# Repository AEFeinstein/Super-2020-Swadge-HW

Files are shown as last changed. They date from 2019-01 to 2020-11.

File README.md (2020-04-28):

# Super 2020 Swadge Hardware

This repo contains hardware files for the Super 2020 Barrel and Banana Swadges, as well as the Swadge Programmer and the Swadge Devkit. [KiCad](https://www.kicad-pcb.org/) is used to work with the project files. [Inkscape](https://inkscape.org/) is used to work with the SVG vectors.

The corresponding hardware repository for the Super 2020 Swadge Firmware [can be found here](https://github.com/AEFeinstein/Super-2020-Swadge-FW).

The Barrel and Banana use the same schematic:
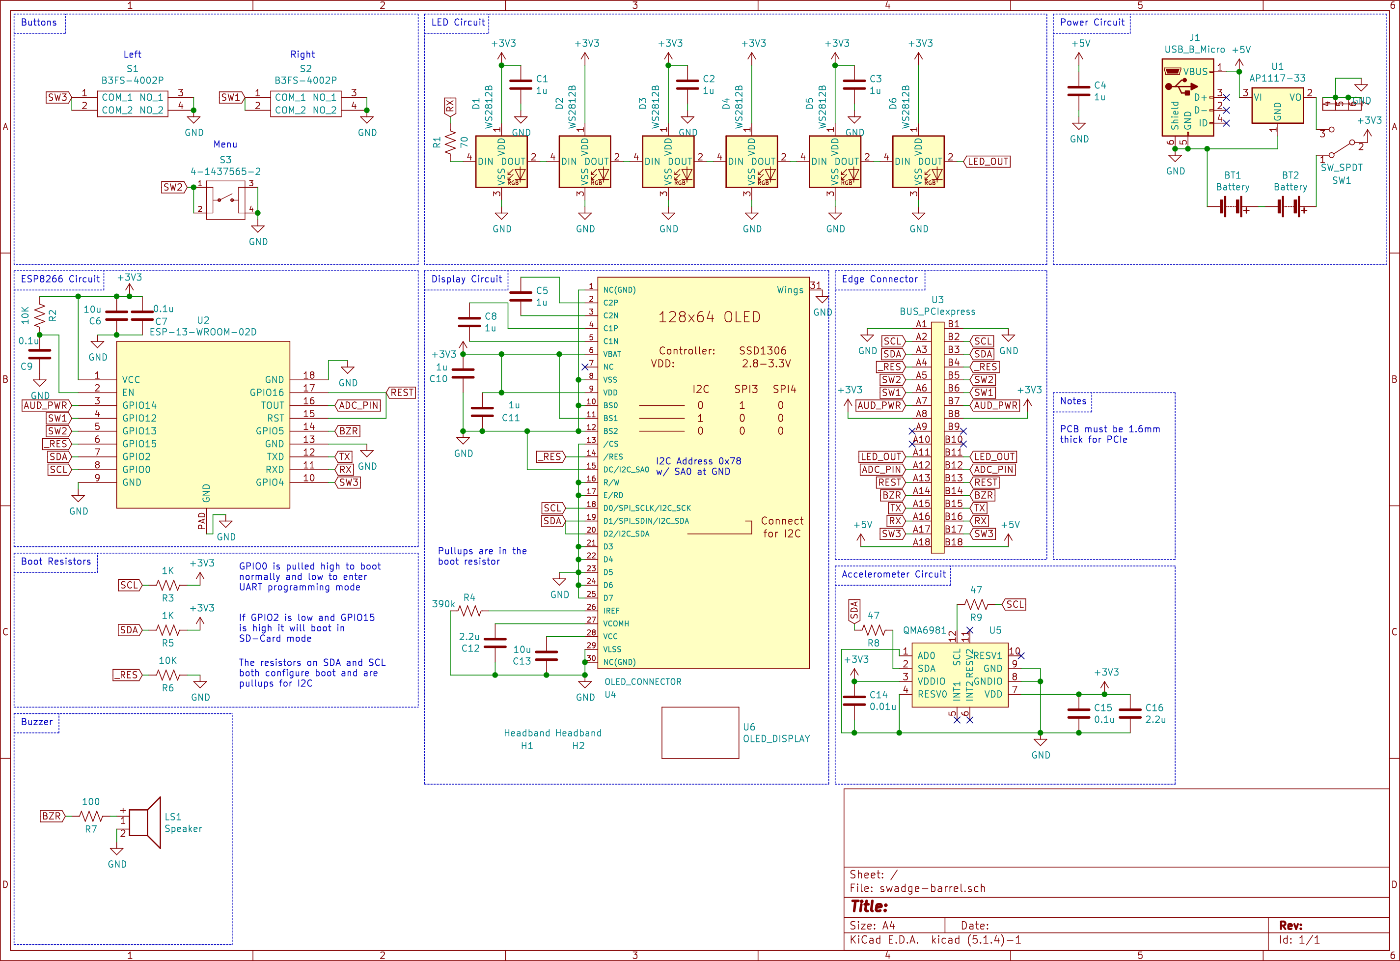
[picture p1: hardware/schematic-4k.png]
Schematic


View this project on [CADLAB.io](https://cadlab.io/project/1918).

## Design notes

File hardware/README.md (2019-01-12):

More libraries can be found at https://github.com/kitspace/kicad_footprints

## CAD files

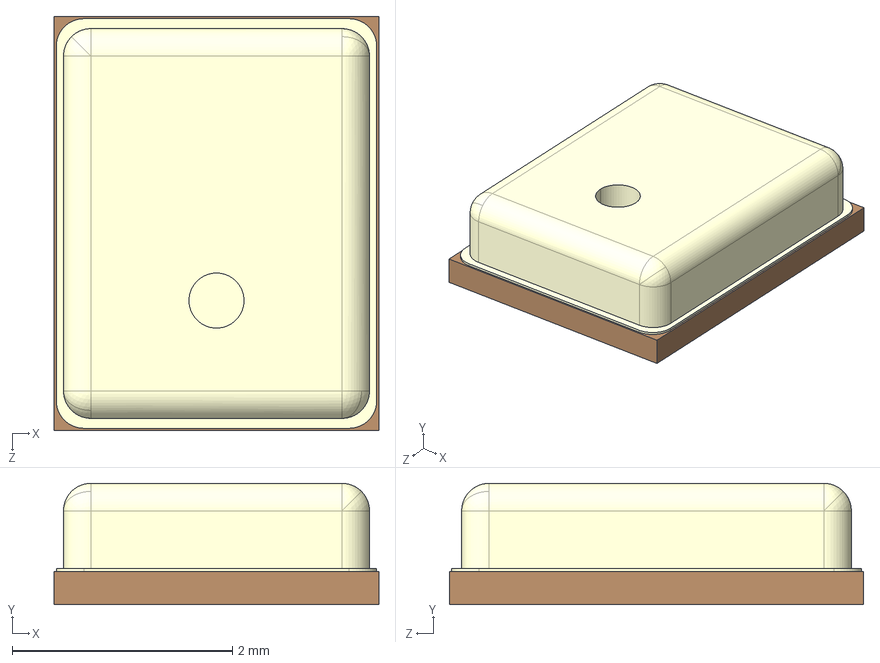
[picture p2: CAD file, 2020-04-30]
hardware/kicad-libs/package3d/AM4311T42A0.step
2.95 x 1.10 x 3.76 mm

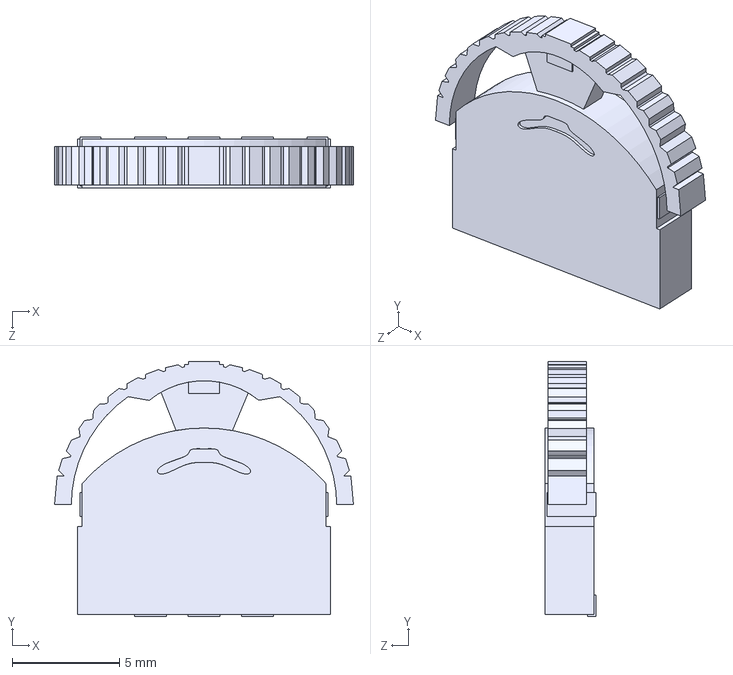
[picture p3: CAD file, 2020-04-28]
hardware/kicad-libs/package3d/NAV_SWITCH.STEP
14.0 x 11.9 x 2.40 mm

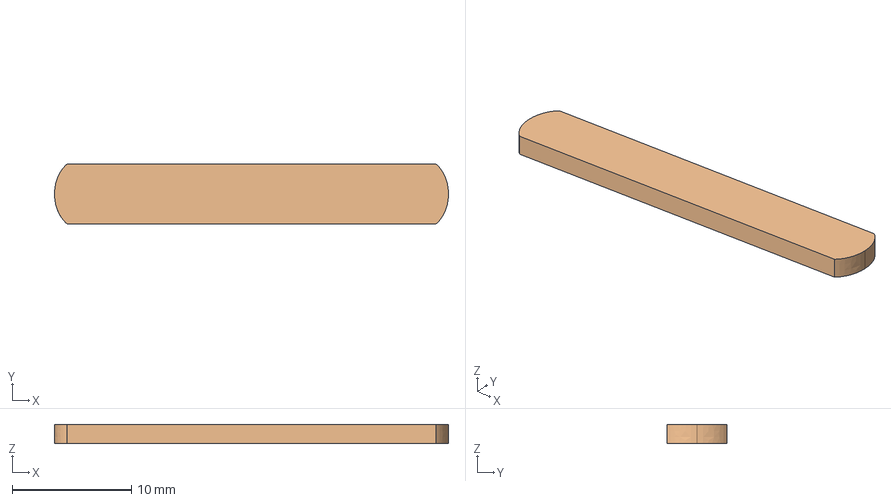
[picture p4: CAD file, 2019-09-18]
hardware/kicad-libs/package3d/headband.step
33.0 x 5.00 x 1.60 mm

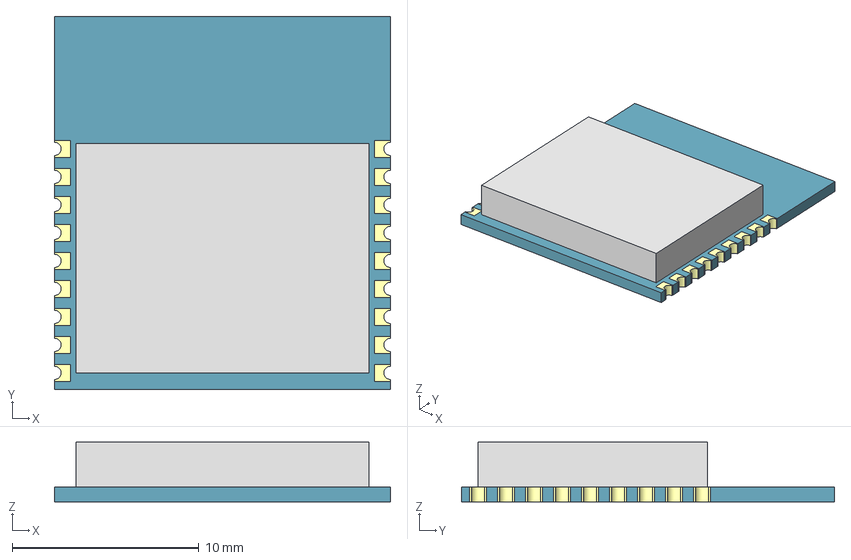
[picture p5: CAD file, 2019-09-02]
hardware/kicad-libs/package3d/ESP-WROOM-02D.stp
18.0 x 20.0 x 3.20 mm

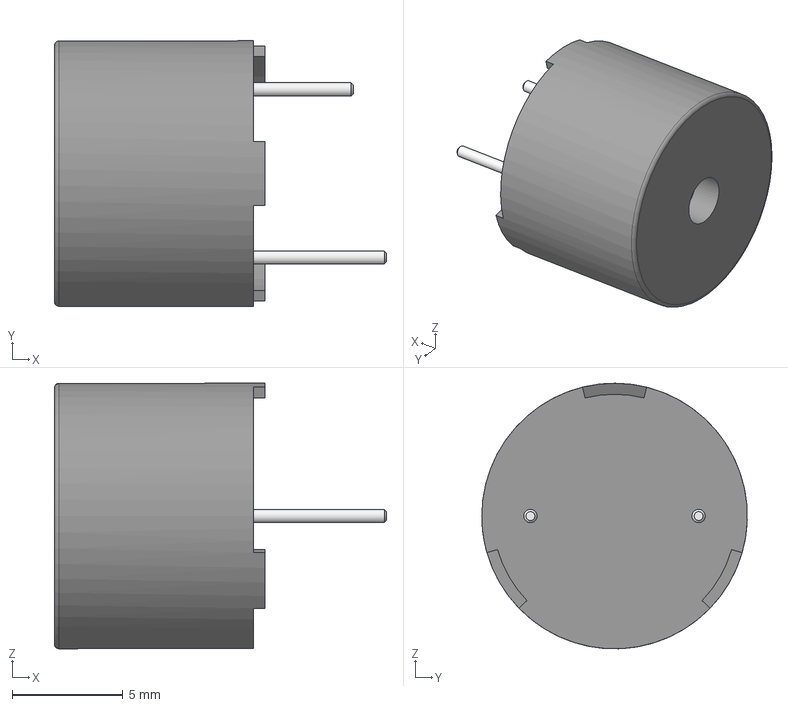
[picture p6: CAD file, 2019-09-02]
hardware/kicad-libs/package3d/Buzzer.step
15.0 x 12.0 x 12.0 mm

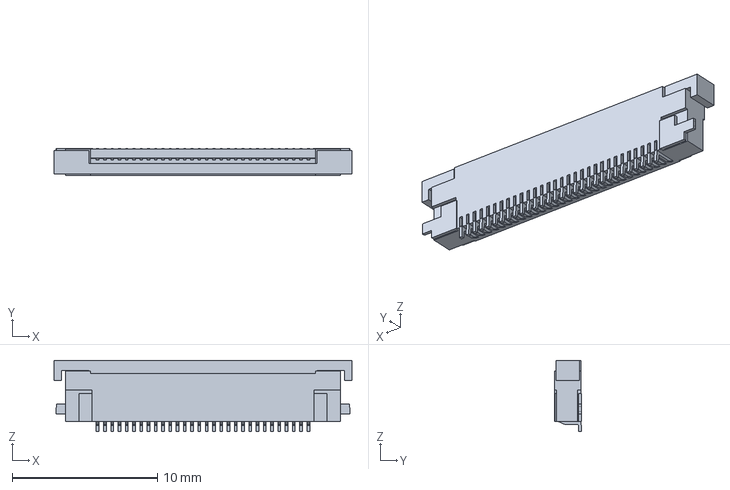
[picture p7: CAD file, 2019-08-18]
hardware/kicad-libs/package3d/ssfv30r_3stlf.stp
20.5 x 1.87 x 4.90 mm

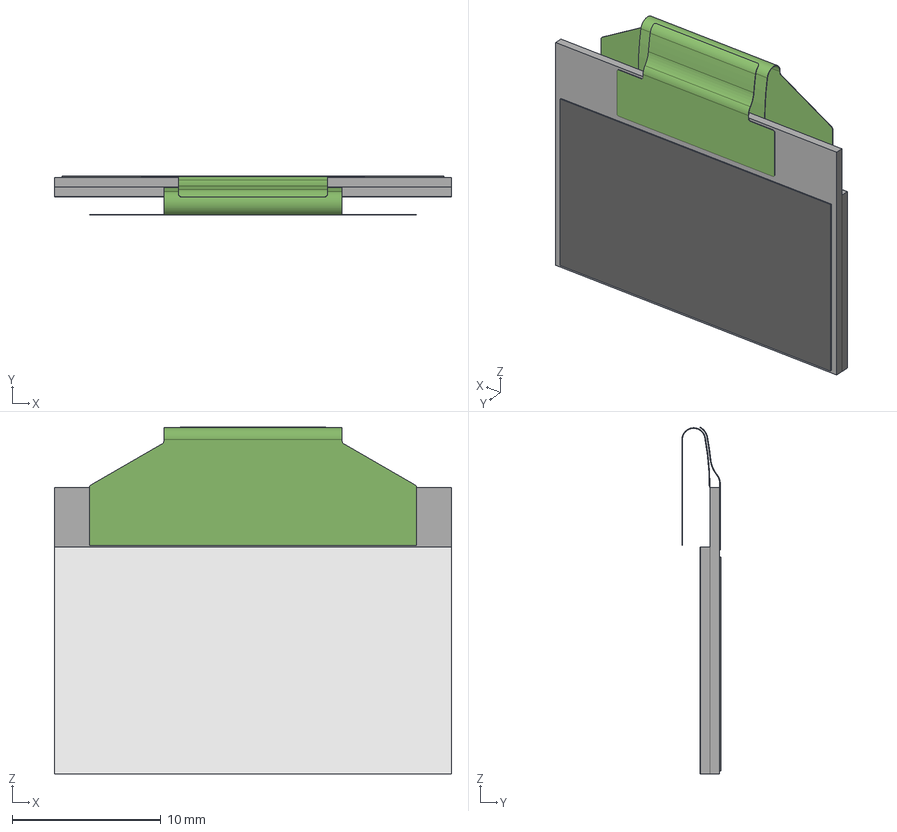
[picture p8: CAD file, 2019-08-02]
hardware/kicad-libs/package3d/oled_curved.step
26.7 x 2.65 x 23.3 mm

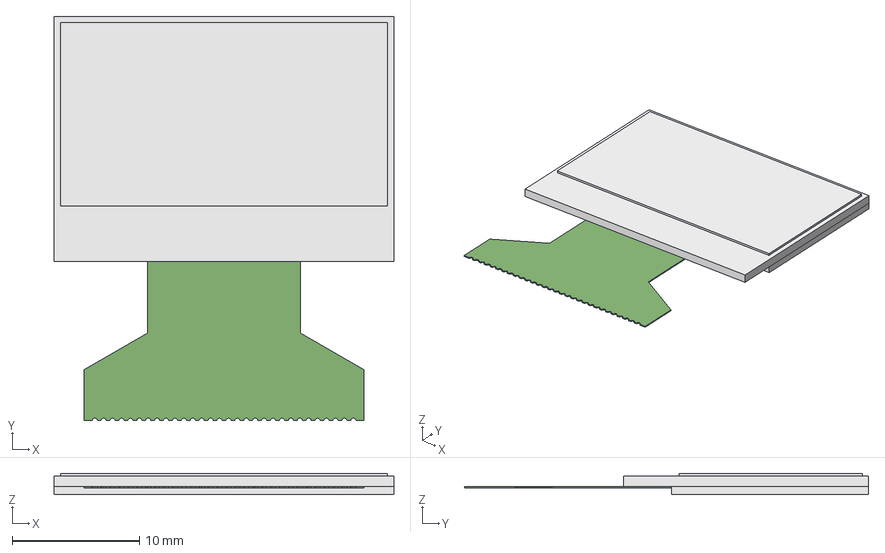
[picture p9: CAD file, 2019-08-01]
hardware/kicad-libs/package3d/oled.FCStd
26.7 x 31.8 x 1.65 mm
Polarizer
Panel
Cap

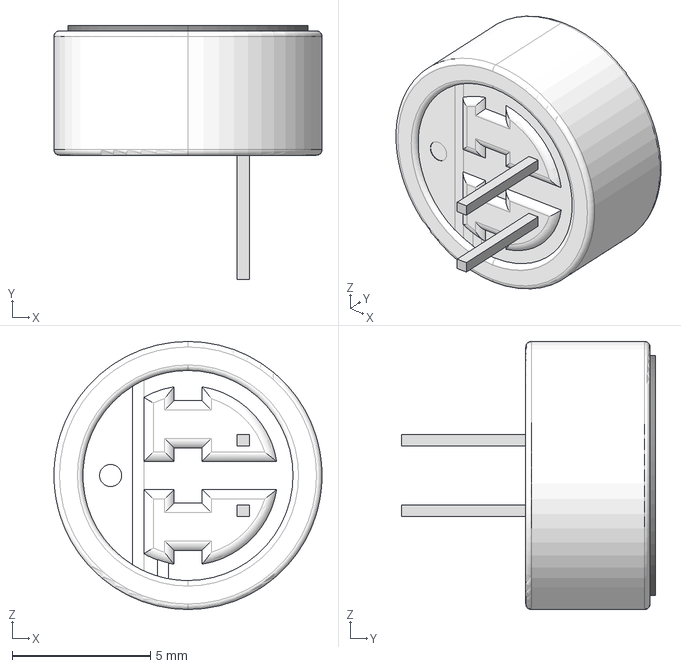
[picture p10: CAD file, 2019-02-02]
hardware/kicad-libs/package3d/CMA-4544PF-W.stp
9.70 x 9.20 x 9.70 mm

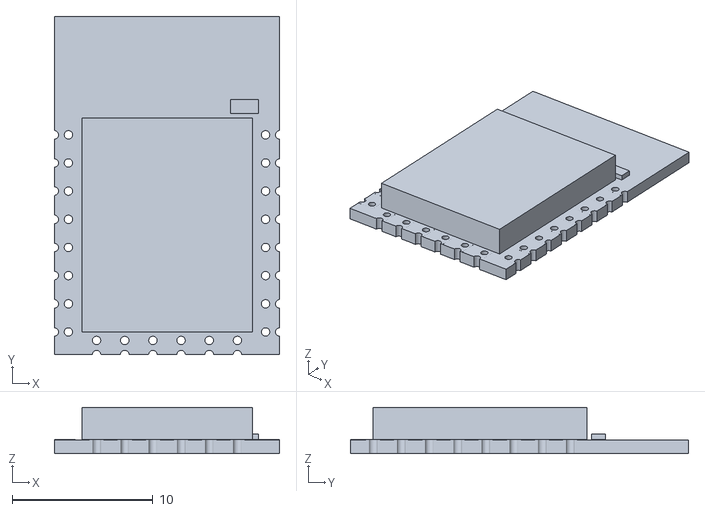
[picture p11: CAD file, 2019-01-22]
hardware/kicad-libs/package3d/ESP-12E_4wings.stl
16.0 x 24.0 x 3.30

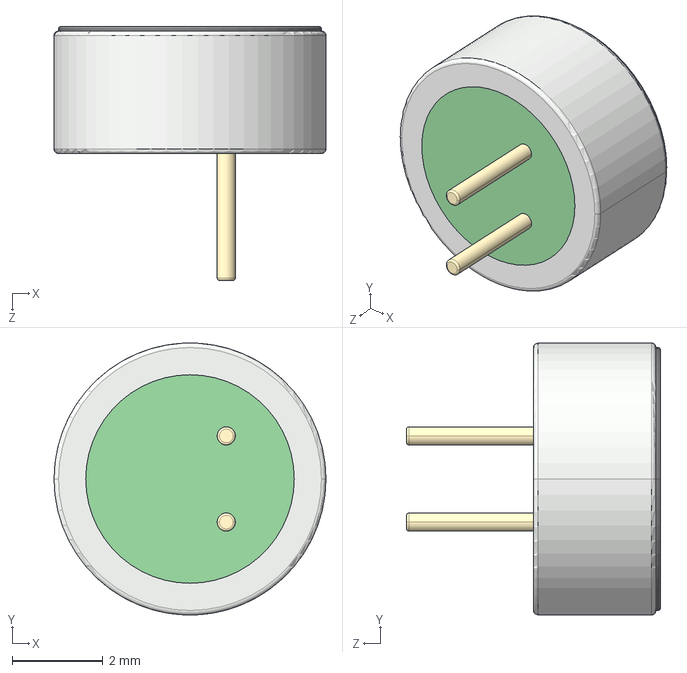
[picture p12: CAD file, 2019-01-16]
hardware/kicad-libs/package3d/MIC POM-2738P-R.STEP
6.00 x 6.00 x 5.60 mm

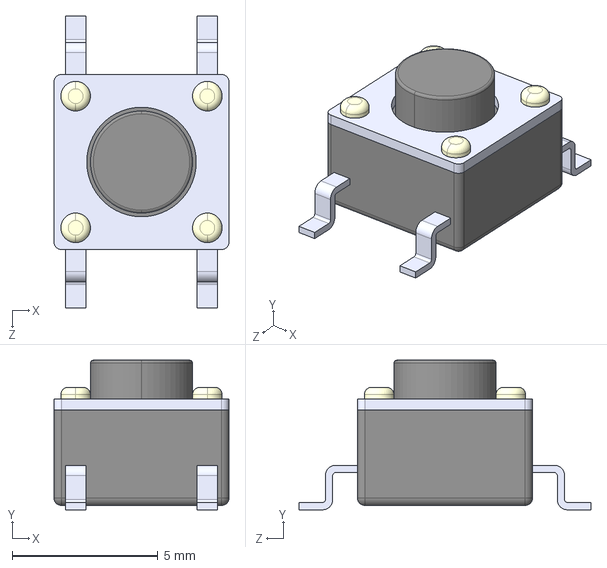
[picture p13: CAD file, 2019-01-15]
hardware/kicad-libs/package3d/FSM4JSMATR--3DModel-STEP-56544.STEP
6.00 x 5.13 x 10.0 mm

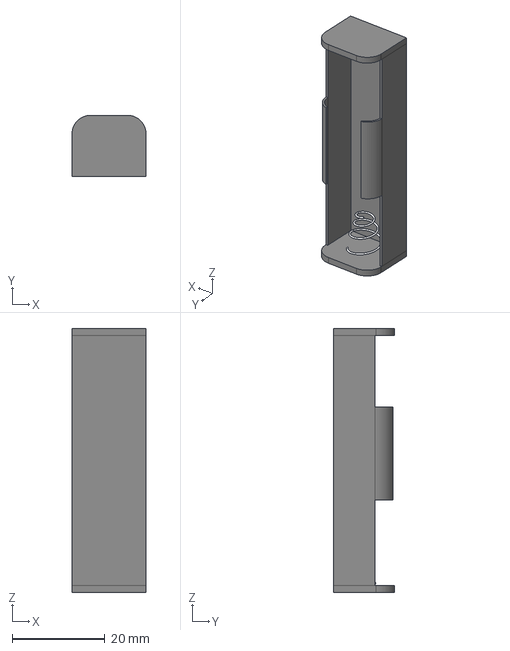
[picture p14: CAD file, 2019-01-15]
hardware/kicad-libs/package3d/KEYSTONE 2460.step
16.0 x 13.3 x 57.0 mm

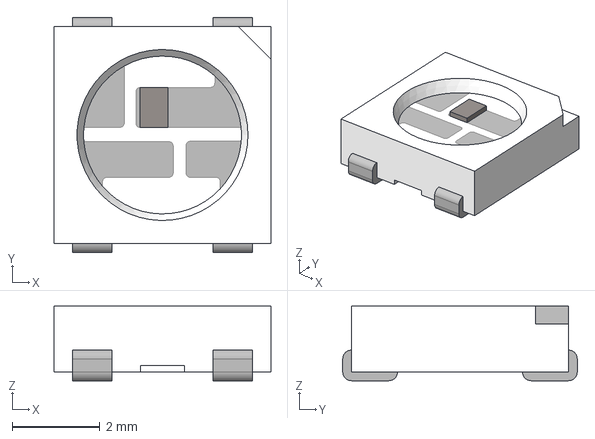
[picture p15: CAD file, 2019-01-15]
hardware/kicad-libs/package3d/WS2812_RGB_LED_updated.stp
4.95 x 5.35 x 1.70 mm

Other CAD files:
hardware/kicad-libs/package3d/ESP-12E.stl
hardware/kicad-libs/package3d/js202011cqn.stp
hardware/kicad-libs/package3d/oled - Copy.FCStd
hardware/kicad-libs/package3d/ESP-12E.scad
hardware/kicad-libs/package3d/MIC POM-2738P-R.SLDPRT
hardware/kicad-libs/package3d/psfv30r_3stlf.prt

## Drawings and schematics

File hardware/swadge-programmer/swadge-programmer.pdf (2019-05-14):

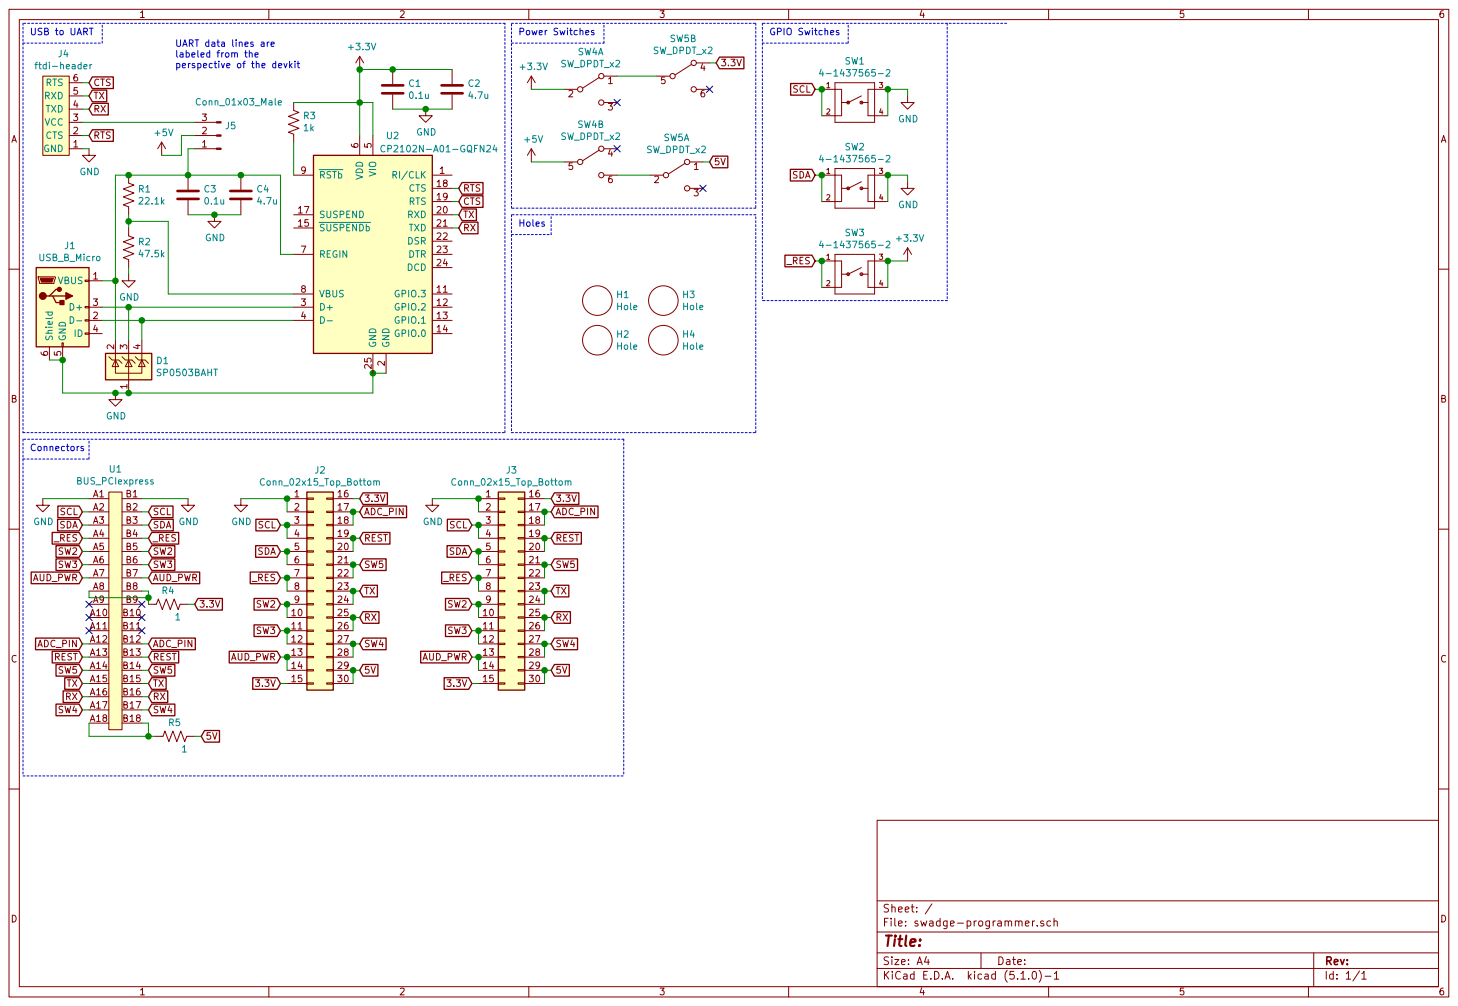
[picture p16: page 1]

ftdi-header TXRX GND

+3.3V UART data lines are
labeled from the
perspective of the devkit 1

RTS CTS CTS RTS
J1 USB_B_Micro GND

2 RXD 20 TXD 21 DSR 22 DTR 23 DCD 24 GND 25 D+ 3 D- 4 VIO

SCL SDA RX
File: swadge-programmer.sch Sheet: / GND
SW2 REST SW4
SW3 AUD_PWR

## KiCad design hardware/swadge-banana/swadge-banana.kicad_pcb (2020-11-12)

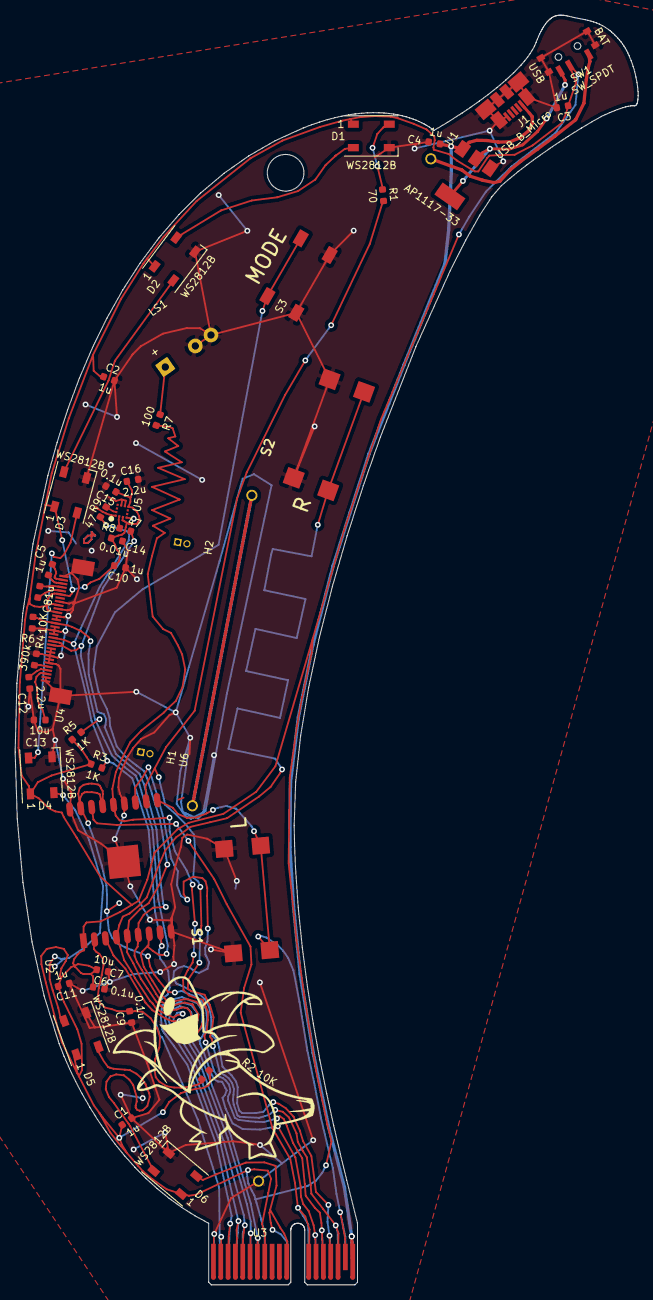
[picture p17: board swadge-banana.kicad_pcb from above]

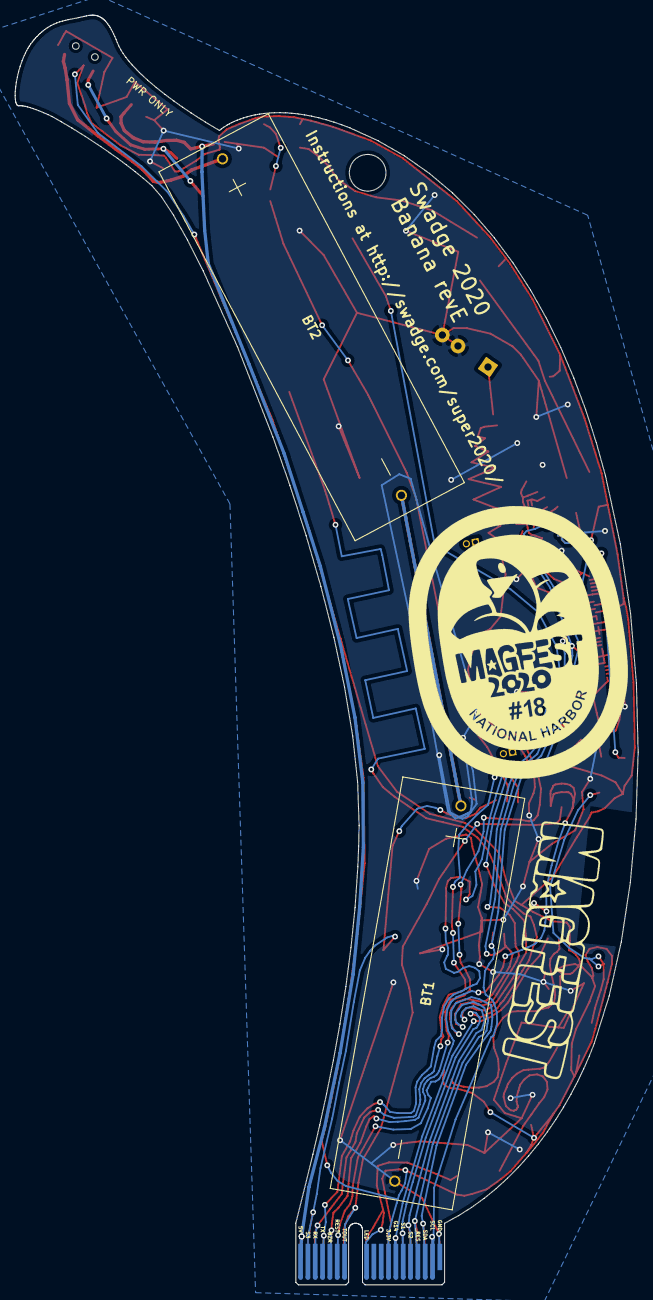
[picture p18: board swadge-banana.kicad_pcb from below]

Board: 2 copper layers, 85.0 x 173.2 mm, 49 parts (3 on the bottom side), 36 nets.

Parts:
BT1, BT2: Battery; 2460
C1, C2, C3, C4, C5, C8, C10, C11: 1u; C_0603_1608Metric
C6, C13: 10u; C_0603_1608Metric
C7, C9, C15: 0.1u; C_0603_1608Metric
C12, C16: 2.2u; C_0603_1608Metric
C14: 0.01u; C_0603_1608Metric
D1, D2, D3, D4, D5, D6: WS2812B; LED_WS2812B_PLCC4_5.0x5.0mm_P3.2mm
H1: Headband
H2: Headband; NULL
J1: USB_B_Micro; USB_Micro-B_Molex_47346-0001
LS1: Speaker; Buzzer_12x9.5RM7.6
R1: 70; R_0603_1608Metric
R2, R6: 10K; R_0603_1608Metric
R3, R5: 1K; R_0603_1608Metric
R4: 390k; R_0603_1608Metric
R7: 100; R_0603_1608Metric
R8, R9: 47; R_0603_1608Metric
Ref**: Val**; bananaraptor_xl
Ref**#2: Val**; banana-label
S1, S2: B3FS-4002P; B3FS4002P
S3: 4-1437565-2; SW_4-1437565-2
SW1: SW_SPDT; SW_SPDT_PCM12
U1: AP1117-33; SOT-223-3_TabPin2
U2: ESP-13-WROOM-02D; ESP-13-WROOM-02
U3: BUS_PCIexpress
U4: OLED_CONNECTOR; ER-OLED0.96-1.3
U5: QMA6981; QMA6981_2
U6: OLED_DISPLAY; NULL

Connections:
+3V3: C1.1, C2.1, C3.1, C6.2, C7.2, C10.2, C11.2, C14.1, C15.1, C16.1, D1.1, D2.1, D3.1, D4.1, D5.1, D6.1, R2.1, R3.1, R5.1, SW1.2, U2.1, U3.A8, U3.B8, U4.6, U4.9, U4.11, U5.3, U5.7
+5V: C4.1, J1.1, U1.3, U3.A18, U3.B18
ADC_PIN: U2.16, U3.A12, U3.B12
AUD_PWR: U2.3, U3.A7, U3.B7
BZR: R7.2, U2.14, U3.A14, U3.B14
GND: BT1.2, C1.2, C2.2, C3.2, C4.2, C6.1, C7.1, C9.1, C10.1, C11.1, C12.1, C13.1, C14.2, C15.2, C16.2, D1.3, D2.3, D3.3, D4.3, D5.3, D6.3, J1.5, J1.6, LS1.2, R4.1, R6.1, S1.3, S1.4, S2.3, S2.4, S3.3, S3.4, SW1.4, SW1.5, SW1.6, SW1.7, U1.1, U2.9, U2.13, U2.18, U2.PAD, U3.A1, U3.B1, U4.1, U4.8, U4.10, U4.12, U4.13, U4.15, U4.16, U4.17, U4.21, U4.22, U4.23, U4.24, U4.25, U4.29, U4.30, U4.31, U5.1, U5.4, U5.8, U5.9
LED_OUT: D6.2, U3.A11, U3.B11
unnamed: BT1.1, BT2.2
unnamed: BT2.1, SW1.1
unnamed: C5.1, U4.2
unnamed: C5.2, U4.3
unnamed: C8.1, U4.4
unnamed: C8.2, U4.5
unnamed: C9.2, R2.2, U2.2
unnamed: C12.2, U4.27
unnamed: C13.2, U4.28
unnamed: D1.2, D2.4
unnamed: D1.4, R1.1
unnamed: D2.2, D3.4
unnamed: D3.2, D4.4
unnamed: D4.2, D5.4
unnamed: D5.2, D6.4
unnamed: LS1.1, R7.1
unnamed: R4.2, U4.26
unnamed: R8.1, U5.2
unnamed: R9.2, U5.12
unnamed: SW1.3, U1.2
REST: U2.15, U2.17, U3.A13, U3.B13
RX: R1.2, U2.11, U3.A16, U3.B16
SCL: R3.2, R9.1, U2.8, U3.A2, U3.B2, U4.18
SDA: R5.2, R8.2, U2.7, U3.A3, U3.B3, U4.19, U4.20
SW1: S2.1, S2.2, U2.4, U3.A6, U3.B6
SW2: S3.1, S3.2, U2.5, U3.A5, U3.B5
SW3: S1.1, S1.2, U2.10, U3.A17, U3.B17
TX: U2.12, U3.A15, U3.B15
_RES: R6.2, U2.6, U3.A4, U3.B4, U4.14

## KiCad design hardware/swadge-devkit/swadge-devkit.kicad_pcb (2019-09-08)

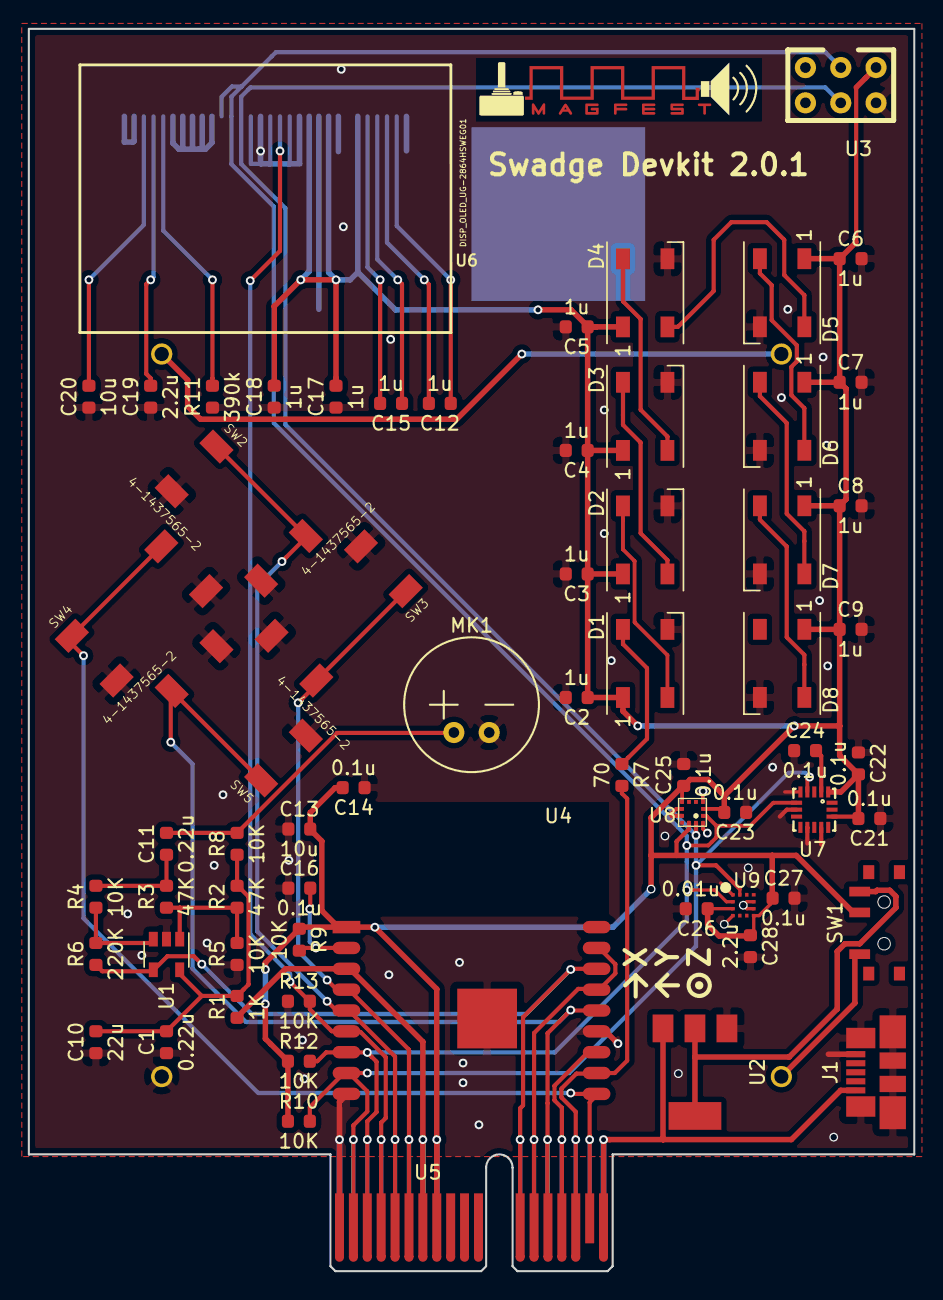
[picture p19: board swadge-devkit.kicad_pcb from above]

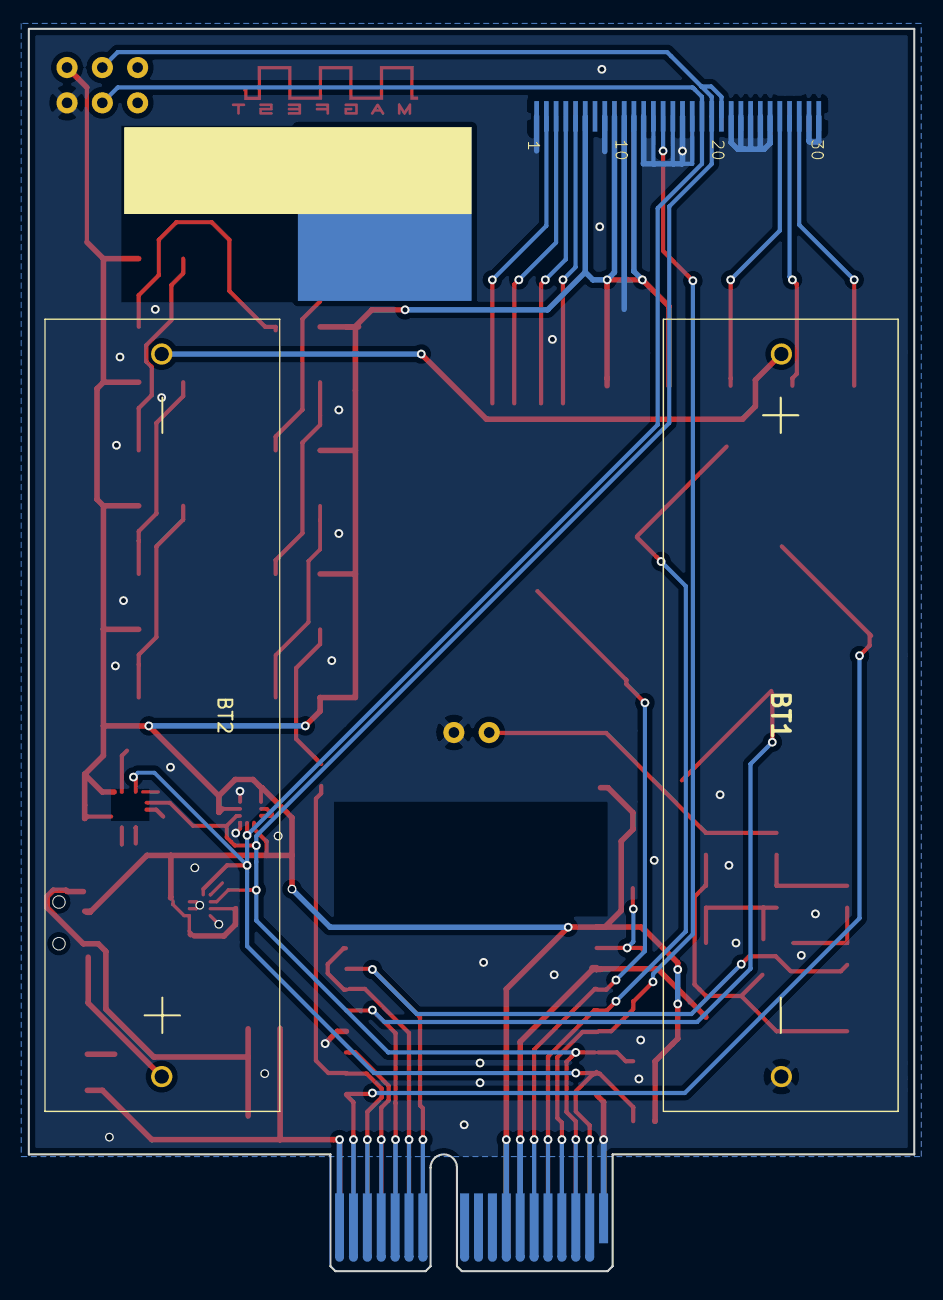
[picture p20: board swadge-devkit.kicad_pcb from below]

Board: 2 copper layers, 63.7 x 89.4 mm, 69 parts (3 on the bottom side), 40 nets.

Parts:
BT1, BT2: Battery; 2460
C1, C11: 0.22u; C_0603_1608Metric
C2, C3, C4, C5, C6, C7, C8, C9, C12, C15, C17, C18: 1u; C_0603_1608Metric
C10: 22u; C_0603_1608Metric
C13, C20: 10u; C_0603_1608Metric
C14, C16, C21, C22, C23, C24, C25, C27: 0.1u; C_0603_1608Metric
C19, C28: 2.2u; C_0603_1608Metric
C26: 0.01u; C_0603_1608Metric
D1, D2, D3, D4, D5, D6, D7, D8: WS2812B; LED_WS2812B_PLCC4_5.0x5.0mm_P3.2mm
J1: USB_B_Micro; USB_Micro-B_Molex_47346-0001
MK1: Microphone; CMA-4544PF-W
R1: 1K; R_0603_1608Metric
R2, R3: 47K; R_0603_1608Metric
R4, R5, R8, R9, R10, R12, R13: 10K; R_0603_1608Metric
R6: 220K; R_0603_1608Metric
R7: 70; R_0603_1608Metric
R11: 390k; R_0603_1608Metric
SW1: SW_SPDT; SW_SPDT_PCM12
SW2, SW3, SW4, SW5: 4-1437565-2; SW_4-1437565-2
U1: GS321-TR; SOT-23-5
U2: AP1117-33; SOT-223-3_TabPin2
U3: SAO
U4: ESP-13-WROOM-02D; ESP-13-WROOM-02
U5: BUS_PCIexpress
U6: DISP_OLED_UG-2864HSWEG01; microbuilder-UG-2864HSWEG01_0.96IN_WRAPAROUND
U7: MMA8452Q; QFN-16_0.5MM
U8: MSA300
U9: QMA6981
svg2mod: G***; pcb_color_swatches
svg2mod#2: G***; MAGFEST_logo_centered_final

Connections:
+3V3: C2.1, C3.1, C4.1, C5.1, C6.1, C7.1, C8.1, C9.1, C13.2, C14.2, C17.2, C18.2, C21.2, C22.2, C23.2, C25.1, C26.1, C27.1, C28.1, D1.1, D2.1, D3.1, D4.1, D5.1, D6.1, D7.1, D8.1, R9.1, R10.1, R12.1, SW1.2, U3.3V3, U4.1, U5.A8, U5.B8, U6.6, U6.9, U6.11, U7.1, U7.14, U8.3, U8.7, U8.11, U9.3, U9.7
+5V: J1.1, U2.3, U5.A18, U5.B18
ADC_PIN: R6.1, U1.4, U4.16, U5.A12, U5.B12
AUD_PWR: R1.1, U4.3, U5.A7, U5.B7
GND: BT1.2, C1.1, C2.2, C3.2, C4.2, C5.2, C6.2, C7.2, C8.2, C9.2, C10.1, C13.1, C14.1, C16.1, C17.1, C18.1, C19.1, C20.1, C21.1, C22.1, C23.1, C24.1, C25.2, C26.2, C27.2, C28.2, D1.3, D2.3, D3.3, D4.3, D5.3, D6.3, D7.3, D8.3, J1.5, J1.6, MK1.1, R5.1, R11.1, R13.1, SW2.3, SW2.4, SW3.3, SW3.4, SW4.3, SW4.4, SW5.3, SW5.4, U1.2, U2.1, U3.GND, U4.9, U4.13, U4.18, U4.PAD, U5.A1, U5.B1, U6.1, U6.8, U6.10, U6.12, U6.13, U6.15, U6.16, U6.17, U6.21, U6.22, U6.23, U6.24, U6.25, U6.29, U6.30, U7.5, U7.7, U7.10, U7.12, U8.1, U8.4, U8.8, U8.9, U9.1, U9.4, U9.8, U9.9
unnamed: BT1.1, BT2.2
unnamed: BT2.1, SW1.1
unnamed: C1.2, C10.2, R1.2, R2.2, R8.1, U1.5
unnamed: C11.1, R3.2, R4.2
unnamed: C11.2, MK1.2, R8.2
unnamed: C12.1, U6.2
unnamed: C12.2, U6.3
unnamed: C15.1, U6.4
unnamed: C15.2, U6.5
unnamed: C16.2, R9.2, U4.2
unnamed: C19.2, U6.27
unnamed: C20.2, U6.28
unnamed: C24.2, U7.2
unnamed: D1.2, D2.4
unnamed: D1.4, R7.1
unnamed: D2.2, D3.4
unnamed: D3.2, D4.4
unnamed: D4.2, D5.4
unnamed: D5.2, D6.4
unnamed: D6.2, D7.4
unnamed: D7.2, D8.4
unnamed: R2.1, R3.1, R5.2, U1.1
unnamed: R4.1, R6.2, U1.3
unnamed: R11.2, U6.26
unnamed: SW1.3, U2.2
REST: U4.15, U4.17, U5.A13, U5.B13
RX: R7.2, U4.11, U5.A16, U5.B16
SCL: R10.2, U3.SCL, U4.8, U5.A2, U5.B2, U6.18, U7.4, U8.12, U9.12
SDA: R12.2, U3.SDA, U4.7, U5.A3, U5.B3, U6.19, U6.20, U7.6, U8.2, U9.2
SW2: SW2.1, SW2.2, U4.5, U5.A5, U5.B5
SW3: SW3.1, SW3.2, U4.4, U5.A6, U5.B6
SW4: SW4.1, SW4.2, U4.10, U5.A17, U5.B17
SW5: SW5.1, SW5.2, U4.14, U5.A14, U5.B14
TX: U4.12, U5.A15, U5.B15
_RES: R13.2, U4.6, U5.A4, U5.B4, U6.14

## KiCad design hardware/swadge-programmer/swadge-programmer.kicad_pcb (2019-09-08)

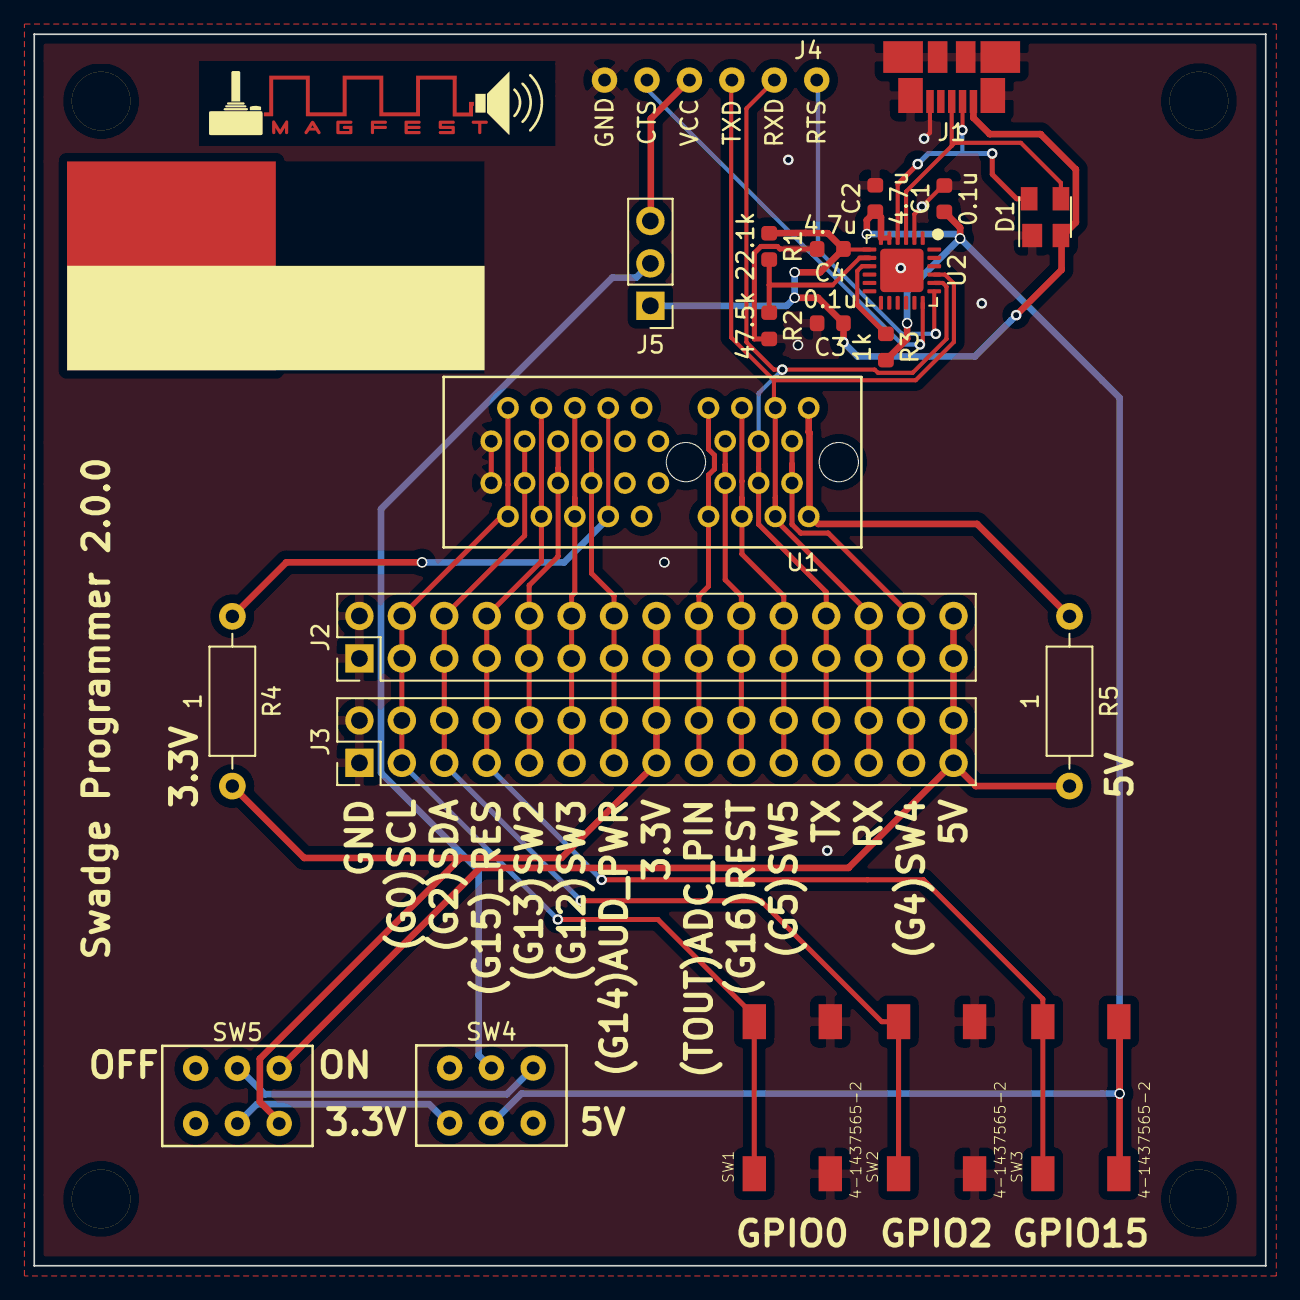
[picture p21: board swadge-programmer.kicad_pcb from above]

Board: 2 copper layers, 73.7 x 73.7 mm, 28 parts (0 on the bottom side), 29 nets.

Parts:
C1, C3: 0.1u; C_0603_1608Metric
C2, C4: 4.7u; C_0603_1608Metric
D1: SP0503BAHT; SOT-143
H1, H2, H3, H4: Hole
J1: USB_B_Micro; USB_Micro-B_Molex_47346-0001
J2, J3: Conn_02x15_Top_Bottom; PinHeader_2x15_P2.54mm_Vertical
J4: ftdi-header
J5: Conn_01x03_Male; PinHeader_1x03_P2.54mm_Vertical
R1: 22.1k; R_0603_1608Metric
R2: 47.5k; R_0603_1608Metric
R3: 1k; R_0603_1608Metric
R4, R5: 1; R_Axial_DIN0207_L6.3mm_D2.5mm_P10.16mm_Horizontal
SW1, SW2, SW3: 4-1437565-2; SW_4-1437565-2
SW4, SW5: SW_DPDT_x2; JS202011CQN
U1: BUS_PCIexpress; 10018784-10210TLF
U2: CP2102N-A01-GQFN24; QFN-24-1EP_4x4mm_P0.5mm_EP2.6x2.6mm
svg2mod: G***; pcb_color_swatches
svg2mod#2: G***; MAGFEST_logo_centered_final

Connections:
3.3V: J2.15, J2.16, J3.15, J3.16, R4.2, SW5.4
5V: J2.29, J2.30, J3.29, J3.30, R5.2, SW5.1
+3V3: C1.1, C2.1, R3.2, SW3.3, SW3.4, SW4.2, U2.5, U2.6
+5V: J5.2, SW4.5
ADC_PIN: J2.17, J2.18, J3.17, J3.18, U1.A12, U1.B12
AUD_PWR: J2.13, J2.14, J3.13, J3.14, U1.A7, U1.B7
CTS: J4.6, U2.19
GND: C1.2, C2.2, C3.2, C4.2, D1.1, J1.5, J1.6, J2.1, J2.2, J3.1, J3.2, J4.1, R2.2, SW1.3, SW1.4, SW2.3, SW2.4, U1.A1, U1.B1, U2.2, U2.25
unnamed: C3.1, C4.1, D1.2, J1.1, J5.1, R1.1, U2.7
unnamed: D1.3, J1.3, U2.3
unnamed: D1.4, J1.2, U2.4
unnamed: J4.3, J5.3
unnamed: R1.2, R2.1, U2.8
unnamed: R3.1, U2.9
unnamed: R4.1, U1.A8, U1.B8
unnamed: R5.1, U1.A18, U1.B18
unnamed: SW4.1, SW5.5
unnamed: SW4.6, SW5.2
REST: J2.19, J2.20, J3.19, J3.20, U1.A13, U1.B13
RTS: J4.2, U2.18
RX: J2.25, J2.26, J3.25, J3.26, J4.4, U1.A16, U1.B16, U2.21
SCL: J2.3, J2.4, J3.3, J3.4, SW1.1, SW1.2, U1.A2, U1.B2
SDA: J2.5, J2.6, J3.5, J3.6, SW2.1, SW2.2, U1.A3, U1.B3
SW2: J2.9, J2.10, J3.9, J3.10, U1.A5, U1.B5
SW3: J2.11, J2.12, J3.11, J3.12, U1.A6, U1.B6
SW4: J2.27, J2.28, J3.27, J3.28, U1.A17, U1.B17
SW5: J2.21, J2.22, J3.21, J3.22, U1.A14, U1.B14
TX: J2.23, J2.24, J3.23, J3.24, J4.5, U1.A15, U1.B15, U2.20
_RES: J2.7, J2.8, J3.7, J3.8, SW3.1, SW3.2, U1.A4, U1.B4

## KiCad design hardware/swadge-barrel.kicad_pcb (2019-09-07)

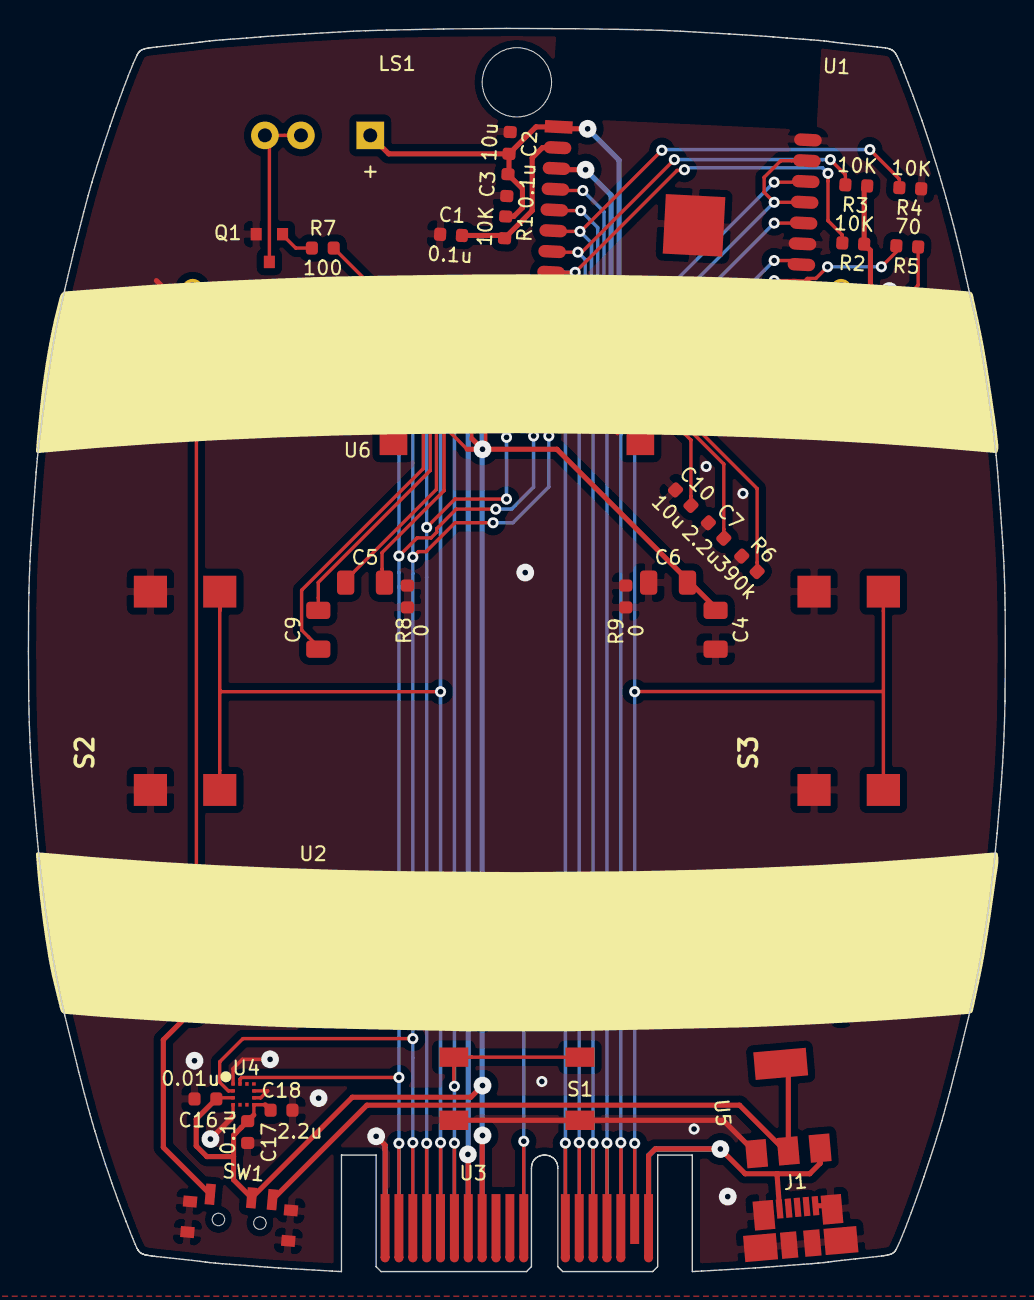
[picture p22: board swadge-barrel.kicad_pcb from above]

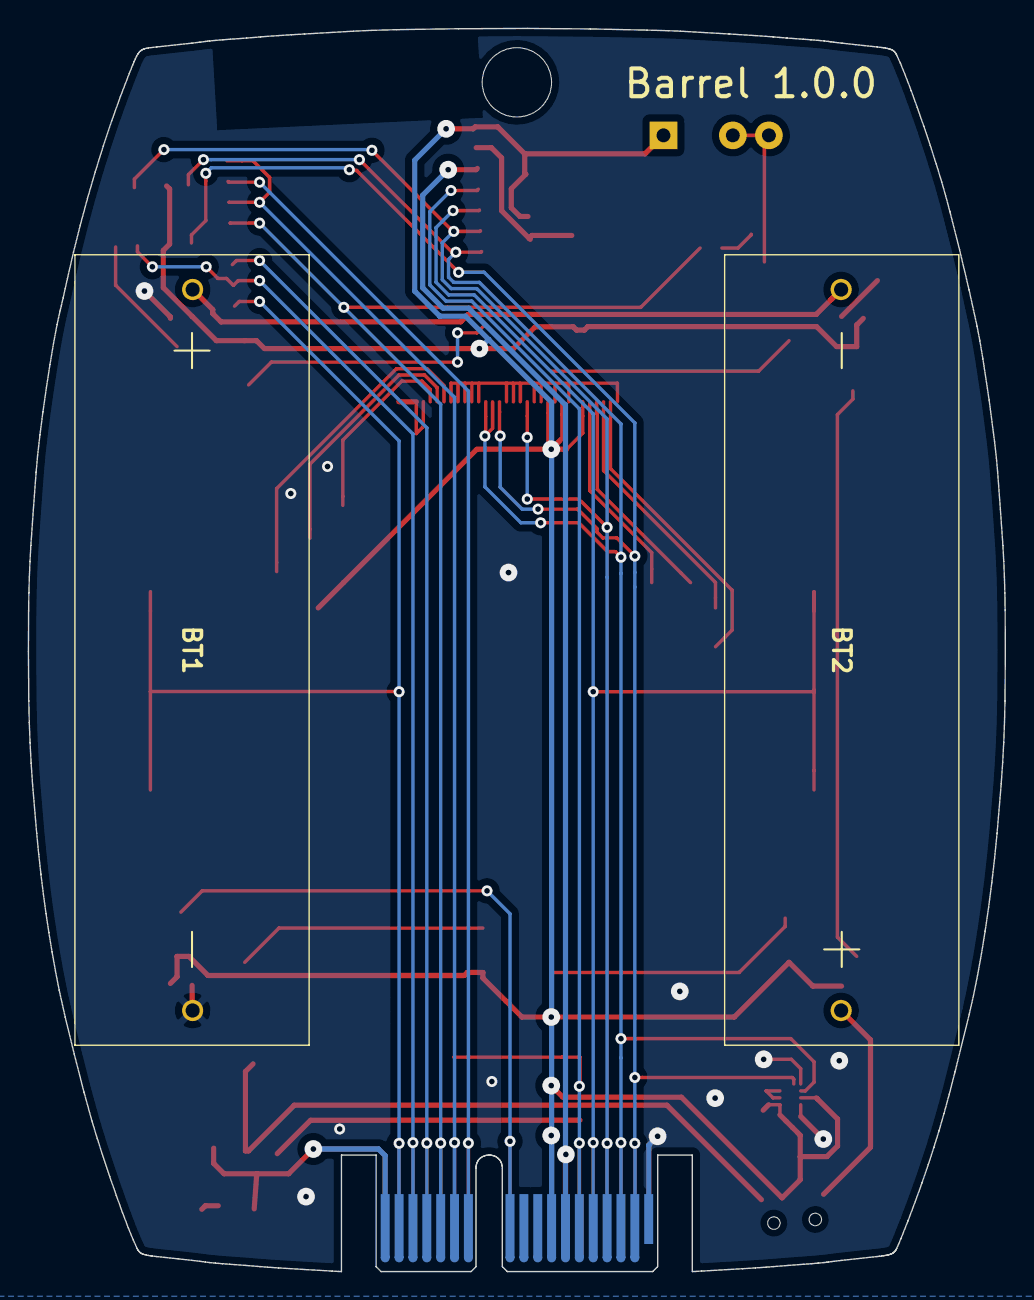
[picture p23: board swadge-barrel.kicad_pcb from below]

Board: 2 copper layers, 70.4 x 89.6 mm, 48 parts (2 on the bottom side), 35 nets.

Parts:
BT1, BT2: Battery; 2460
C1, C3, C17: 0.1u; C_0603_1608Metric
C2, C10: 10u; C_0603_1608Metric
C4, C5, C6, C9: 1u; C_1206_3216Metric
C7, C18: 2.2u; C_0603_1608Metric
C8, C11, C12, C13, C14, C15: 1u; C_0603_1608Metric
C16: 0.01u; C_0603_1608Metric
D1, D2, D3, D4, D5, D6: WS2812B; LED_WS2812B_PLCC4_5.0x5.0mm_P3.2mm
J1: USB_B_Micro; USB_Micro-B_Molex_47346-0001
LS1: Speaker; Buzzer_12x9.5RM7.6
Q1: Q_NPN_BEC; SOT-23
R1, R2, R3, R4: 10K; R_0603_1608Metric
R5: 70; R_0603_1608Metric
R6: 390k; R_0603_1608Metric
R7: 100; R_0603_1608Metric
R8, R9: 0; R_0603_1608Metric
S1: 4-1437565-2; SW_4-1437565-2
S2, S3: B3FS-4002P; B3FS4002P
SW1: SW_SPDT; SW_SPDT_PCM12
U1: ESP-13-WROOM-02D; ESP-13-WROOM-02
U2: OLED_DISPLAY; NULL
U3: BUS_PCIexpress
U4: QMA6981
U5: AP1117-33; SOT-223-3_TabPin2
U6: OLED_CONNECTOR; oled-flat_copy

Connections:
+3V3: C2.2, C3.2, C4.2, C6.2, C8.1, C11.1, C12.1, C13.1, C14.1, C15.1, C16.1, C17.1, C18.1, D1.1, D2.1, D3.1, D4.1, D5.1, D6.1, LS1.1, R1.1, R2.1, R3.1, SW1.2, U1.1, U3.A8, U3.B8, U4.3, U4.7, U6.6, U6.9, U6.11
+5V: J1.1, U3.A18, U3.B18, U5.3
ADC_PIN: U1.16, U3.A12, U3.B12
AUD_PWR: U1.3, U3.A7, U3.B7
BZR: R7.2, U1.14, U3.A14, U3.B14
GND: BT1.2, C1.1, C2.1, C3.1, C4.1, C6.1, C7.1, C8.2, C10.1, C11.2, C12.2, C13.2, C14.2, C15.2, C16.2, C17.2, C18.2, D1.3, D2.3, D3.3, D4.3, D5.3, D6.3, J1.5, J1.6, Q1.2, R4.1, R6.1, R8.1, R8.2, R9.1, R9.2, S1.3, S1.4, S2.3, S2.4, S3.3, S3.4, SW1.4, SW1.5, SW1.6, SW1.7, U1.9, U1.13, U1.18, U1.PAD, U3.A1, U3.B1, U4.1, U4.4, U4.8, U4.9, U5.1, U6.1, U6.8, U6.10, U6.12, U6.13, U6.15, U6.16, U6.17, U6.21, U6.22, U6.23, U6.24, U6.25, U6.29, U6.30
LED_OUT: D6.2, U3.A11, U3.B11
unnamed: BT1.1, BT2.2
unnamed: BT2.1, SW1.1
unnamed: C1.2, R1.2, U1.2
unnamed: C5.1, U6.4
unnamed: C5.2, U6.5
unnamed: C7.2, U6.27
unnamed: C9.1, U6.2
unnamed: C9.2, U6.3
unnamed: C10.2, U6.28
unnamed: D1.2, D2.4
unnamed: D1.4, R5.1
unnamed: D2.2, D3.4
unnamed: D3.2, D4.4
unnamed: D4.2, D5.4
unnamed: D5.2, D6.4
unnamed: LS1.2, Q1.3
unnamed: Q1.1, R7.1
unnamed: R6.2, U6.26
unnamed: SW1.3, U5.2
REST: U1.15, U1.17, U3.A13, U3.B13
RX: R5.2, U1.11, U3.A16, U3.B16
SCL: R2.2, U1.8, U3.A2, U3.B2, U4.12, U6.18
SDA: R3.2, U1.7, U3.A3, U3.B3, U4.2, U6.19, U6.20
SW1: S1.1, S1.2, U1.4, U3.A6, U3.B6
SW2: S2.1, S2.2, U1.5, U3.A5, U3.B5
SW3: S3.1, S3.2, U1.10, U3.A17, U3.B17
TX: U1.12, U3.A15, U3.B15
_RES: R4.2, U1.6, U3.A4, U3.B4, U6.14

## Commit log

2019-01-12 Added initial project with a single ESP-12F
    [swadge-devkit.kicad_pcb, swadge-devkit.sch]
2019-01-12 Worked on the schematic
    Added accelerometer part lib
    [swadge-devkit.kicad_pcb, swadge-devkit.sch]
2019-01-12 Did a bit of routing
    [swadge-devkit.kicad_pcb, swadge-devkit.sch]
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2019-01-14 Added I2C display
    Schematic copied from https://github.com/adafruit/Adafruit-1.3inch-128x64-Mono-OLED-PCB
    [swadge-devkit.kicad_pcb, swadge-devkit.sch]
2019-01-14 Better silkscreen & GND plane fill
    [swadge-devkit.kicad_pcb]
2019-01-14 Add local library paths, 3D model for ESP
    [swadge-devkit.kicad_pcb]
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2019-01-15 Added WS2812B 3D model. Fixed MMA8452Q 3D model
    [WS2812_RGB_LED_updated.stp, swadge-devkit.kicad_pcb]
2019-01-15 Added more 3D parts!
    [FSM4JSMATR--3DModel-STEP-56544.STEP, KEYSTONE 2460.step, swadge-devkit.kicad_pcb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]
2019-01-16 Made a new microphone footprint, added 3D microphone model
    [MIC POM-2738P-R.SLDPRT, MIC POM-2738P-R.STEP, swadge-devkit.kicad_pcb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]
2019-01-17 Replaced MMA8452Q accelerometer with MSA300
    [swadge-devkit.kicad_pcb, swadge-devkit.sch]
2019-01-19 Added second accelerometer, MMA8452Q
    [swadge-devkit.kicad_pcb, swadge-devkit.sch]
2019-01-19 Added programmer schematic and layout
    [swadge-devkit.sch, swadge-programmer.kicad_pcb, swadge-programmer.sch]
2019-01-19 Added power switches & pin headers to programmer
    [swadge-programmer.kicad_pcb, swadge-programmer.sch]
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2019-01-24 Made board symmetrical wrt. the PCI connector
    Moved batteries to the back, imported Swadge 2019 battery footprint
    Reoriented accelerometers so they match orientation
    Fattened up power traces
    [swadge-devkit.kicad_pcb, swadge-devkit.sch]
2019-01-25 Moved mic away from battery
    Updated DRC to use CNLohr's numbers
    [swadge-devkit.kicad_pcb]
2019-01-30 Moved all programmer parts into this repo
    Resized programmer, rerouted programmer, added holes
    [swadge-programmer.kicad_pcb, swadge-programmer.sch]
2019-02-02 Updated library with manufacturing info followiong cnlohr's kicad_for_mfg
    Updated all traces (except accelerometer traces) to 0.0077in
    Replaced microphone with bigger, cheaper one
    [CMA-4544PF-W.stp, swadge-devkit.kicad_pcb, swadge-devkit.sch]
2019-02-02 Removed NOBOM from parts which didn't need it Added BOM tools
    [swadge-devkit.sch]
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2019-02-22 Added SAO Moved mic out of the way of buttons Swapped 1.3" display for 0.96" display Linked vishay display instead of adafruit one
    [swadge-devkit.kicad_pcb, swadge-devkit.sch]
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2019-02-23 Added digikey part numbers for passives Updated PCB color swatch, logo Added name & version to PCB
    [swadge-devkit.kicad_pcb, swadge-devkit.sch]
2019-02-23 Updated digikey part numbers Added graphics to swadge programmer PCB
    [swadge-devkit.sch, swadge-programmer.kicad_pcb, swadge-programmer.sch]
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2019-02-23 Added PCB note Output manufacture files for 1.0.0
    [swadge-devkit.kicad_pcb, swadge-devkit.sch, swadge-programmer.kicad_pcb]
2019-03-11 Added digikey part for PCIe connector on the programmer
    [swadge-programmer.sch]
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2019-04-02 #16 replace GPIO switches with buttons in schematic
    [swadge-programmer.sch]
2019-04-02 #7 Cross RX and TX coming off CP2102n in schematic
    [swadge-programmer.sch]
2019-04-02 #5 Added FTDI-ordered breakout of all UART pins
    [swadge-programmer.sch]
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2019-04-02 #1 #2 #3 #5 #6 #7 #16 Routed PCB
    [swadge-programmer.kicad_pcb, swadge-programmer.sch]
2019-04-02 Swapped RX/TX on FTDI header, added voltage jumper selector
    [swadge-programmer.kicad_pcb, swadge-programmer.sch]
2019-04-04 #11 Remap GPIO, remove extra I2C pullups, remove SPI lines
    [swadge-devkit.sch]
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2019-04-04 #15 flipped mic pads in footprint
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2019-04-04 #14 Replaced ESP-12F with ESP-WROOM-02D
    [swadge-devkit.kicad_pcb, swadge-devkit.sch]
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2019-04-07 #12 Swapped USB & Power Switch
    [swadge-devkit.kicad_pcb]
2019-04-08 #19 Update AA holder footprints, move them further apart too
    [swadge-devkit.kicad_pcb, swadge-devkit.sch]
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2019-04-09 Shortened board
    [swadge-devkit.kicad_pcb]
2019-04-10 #4 Add Rubber foot to hole part, update digikey values
    [swadge-programmer.sch]
2019-04-10 Fix datasheets
    [swadge-programmer.sch]
2019-04-10 Fix datasheets some more
    [swadge-programmer.sch]
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2019-05-17 Added back missing battery, PCB art
    [swadge-devkit.kicad_pcb]
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2019-05-17 Fixed silkscreen
    [swadge-devkit.kicad_pcb]
2019-05-28 Added new QMA6981 footprint, no more DRC errors
    [swadge-devkit.kicad_pcb, swadge-devkit.sch]
2019-05-28 Fixed DRC error, silkscreen
    [swadge-devkit.kicad_pcb]
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2019-08-02 Swapped 3D OLED model for the devkit
    [swadge-devkit.kicad_pcb]
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2019-08-18 Reworked banana, started laying it out
    [psfv30r_3stlf.prt, ssfv30r_3stlf.stp, swadge-banana.kicad_pcb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]
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2019-08-22 Added THT buzzer to barrel board
    [swadge-barrel.kicad_pcb, swadge-barrel.sch]
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2019-09-02 fixed all DRC errors
    [swadge-barrel.kicad_pcb]
2019-09-02 Moved a lot of silk to F.Fab. Updated buzzer footprint
    [Buzzer.step, swadge-barrel.kicad_pcb, swadge-barrel.sch]
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2019-09-04 Switched to elecrow FPC part. moved around things. added art, version
    [swadge-barrel.kicad_pcb]
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2019-09-07 Replaced 0805 caps with 1206 caps
    [swadge-barrel.kicad_pcb, swadge-barrel.sch]
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2019-09-08 Fixed 3D model paths, Updated to version 1.0.1
    [swadge-barrel.kicad_pcb]
2019-09-08 Fixed 3d model paths for all projects
    [swadge-banana.kicad_pcb, swadge-devkit.kicad_pcb, swadge-programmer.kicad_pcb]
2019-09-08 Fixed some bent traces
    [swadge-barrel.kicad_pcb]
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2019-09-16 Flipped OLED contacts, haven't routed them yet #24
    [swadge-barrel.kicad_pcb, swadge-barrel.sch]
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2019-09-23 Reset banana board to a blank slate for cnlohr
    [swadge-banana.kicad_pcb, swadge-banana.sch]
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2019-10-19 Added vertical banding, shifted parts to avoid the bands
    [swadge-barrel.kicad_pcb]
2019-10-22 Removed transistor from the buzzer circuit. It's louder this way Updated buzzer part info Updated headband part info Adjusted orientation of accelerometer passives
    [swadge-barrel.kicad_pcb, swadge-barrel.sch]
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2019-10-24 Removed some capacitance from 3.3V, added some capacitance to 5V
    [swadge-barrel.kicad_pcb, swadge-barrel.sch]
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2019-10-24 Added manufacturing output in pcb file, ignored manufacturing dir
    [swadge-barrel.kicad_pcb]
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2019-10-24 Added mfg folder to PCB file, ignored mfg folder
    [swadge-barrel-headband.kicad_pcb]
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2019-10-26 Added power parts to Swadge_Parts library Modified swadge-banana.sch to use new power parts Removed cnlohr specific paths from sym-lib-table
    [swadge-banana.sch]
2019-10-26 Modified barrel and programmer to use Swadge_Parts's power parts
    [swadge-barrel.sch, swadge-programmer.sch]
2019-10-26 Copied schematic from barrel, again Reimported schematic into layout, fixed capacitor changes Fixed one DRC violation
    [swadge-banana.kicad_pcb, swadge-banana.sch]
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2019-10-28 Properly aligned accelerometer Moved C15 closer to accelerometer
    [swadge-banana.kicad_pcb]
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2019-11-01 Changed headband art to a simple square wave
    [swadge-barrel-headband.kicad_pcb]
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2019-11-09 Replaces test text with URL
    [swadge-barrel.kicad_pcb]
2019-11-10 Updated & added silkscreen * Buttons * PCIe connector * Version * Tilted MAGFEST logo * Added note that USB is power-only * Website text
    [swadge-barrel.kicad_pcb]
2019-11-10 Added & Updated silkscreen * Labeled buttons, power switch * Labeled PCIe connector * Added funkus & logo graphics * Added note that USB is power only * Added instruction URL * Updated revision
    [swadge-banana.kicad_pcb]
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2019-11-11 Moved R2 back to original position so stencil & pick-n-place won't change Made bananaraptor even bigger
    [swadge-banana.kicad_pcb]
2019-11-11 Readded missing batteries, filled zones
    [swadge-banana.kicad_pcb]
2019-11-12 Added banana label to the back of the banana Rotated Lil'B on the front of the banana
    [swadge-banana.kicad_pcb]
2019-11-12 Changed I2C pullups to 1K Updated digikey part numbers on BOM
    [swadge-barrel.kicad_pcb, swadge-barrel.sch]
2019-11-12 (Banana this time) Changed I2C pullups to 1K Updated digikey part numbers on BOM
    [swadge-banana.kicad_pcb, swadge-banana.sch]
2019-11-12 Made I2C traces to accel less right angly
    [swadge-barrel.kicad_pcb]
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2019-11-20 Added new QMA6981 part with larger pads Updated banana and barrel with new pads
    [swadge-banana.kicad_pcb, swadge-banana.sch, swadge-barrel.kicad_pcb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]
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2019-12-31 Fix path for accel 3D object
    [swadge-banana.kicad_pcb, swadge-barrel.kicad_pcb]
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2020-11-11 Fix new 3D models
    [swadge-barrel.kicad_pcb]
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
